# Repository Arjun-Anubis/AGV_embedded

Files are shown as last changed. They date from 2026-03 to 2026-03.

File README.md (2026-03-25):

# AGV Embedded Systems Selection Round

I attempted the first two tasks, the PCB design of the nPM1100 and the digital design of CORDIC in verilog

## Structure of the Repository

The task folders each have their directories, within the first level, the README.md
will have the info required to run the programs including installation directions etc
The documentation and approach will be in the doc folder

## Progress on the tasks

### PCB design

1. Base task (design req)
    a. Schematic
    b. Design 
    c. BOM
2. Expose CHG, ERR, ISET, MODE, SHPHLD and SHPACT pins to MCU
3. Status LEDs
4. Battery Monitoring

Constraints
1. Max Dimensions
2. SMD, top mounted
3. 0403-0805 footprints
4. Input via 2 pin header       NOTE
5. Max 4 copper layers
6. QFN24 footprint with used central thermal pad
7. 3V output
8. 200mA output

### Digital Design

1. Design
    a. n-bit adder
    b. complemts and subtracter
    c. comparator
    d. look up table
    e. 8 bit to 12 bit CORDIC
2. Test Bench
3. GTKWave

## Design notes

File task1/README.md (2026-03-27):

# PCB Design with the nPM1100 PMIC

This is documentaion written after the fact, if you want to read the 
design process as it was done, consider [the old readme](./README.old.md). 
I'll explain my model in two layers of abstraction.

1. Behaviour level
2. Pin level

## Behaviour level

A PMIC is typically used on a portable electronic device: like a mobile phone, 
a gaming mouse, a drone etc. it abstracts away the details of charging and battery
and provides a stable voltage and current to the microcontroller chip.

This means that our chip has the following

1. input (USB or barrel)
2. output (microcontroller)
3. inout (battery, which has to be charged and discharged)

and similarly out PMIC can itself be divided into subsystems

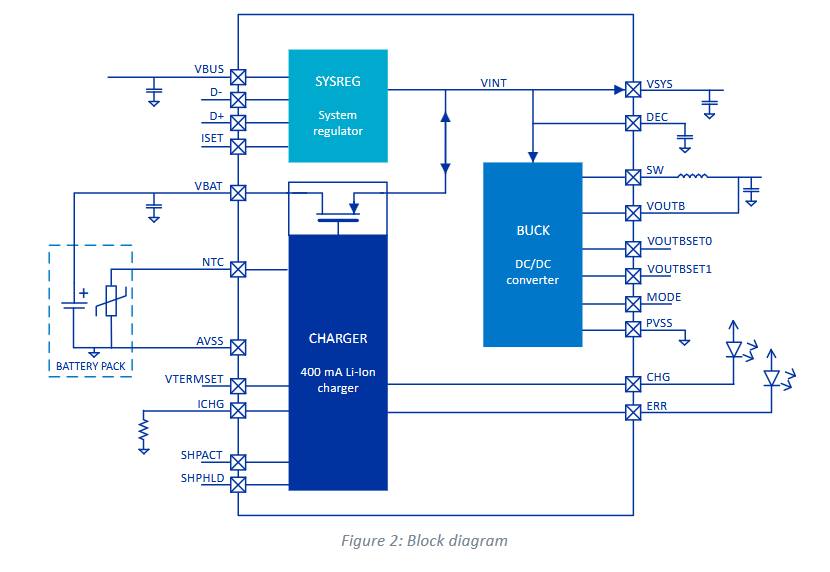
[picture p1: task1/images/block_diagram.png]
Block diagram


Now that we understand what the chip does on a high level, we need to check if this
is indeed the right chip for us to use, we can decide this by looking at the 
design requirements:

1. 3V DC output
2. 200mA charging
3. 35mmx35mm for the entire PCB

and we have been told to use the nordic semiconductor nPM1100 PMIC
with the QFN24 variant, which is 4mmx4mm.

First we make a ballpark estimate, then we consult the data sheet, the voltage ~ 3V
is pretty typical for a microcontroller so that makes sense, and the charging
current 200mA is pretty typical for a small LiPo battery, in say a drone.

The consumption current is probably less than that, and that would make the 
outut power a few hundred mW, which is also reasonable for a 35mmx35mm
chip to discharge

Now we consult the datasheet

### Package size

The 4mmx4mm package does indeed exist

> nPM1100 is an integrated Power Management IC (PMIC) with a linear-mode lithium-ion/lithium-polymer battery charger in a compact 2.1x2.1 mm WLCSP or 4.0x4.0 mm QFN package. It has a highly efficient DC/ DC buck regulator with configurable dual mode output.

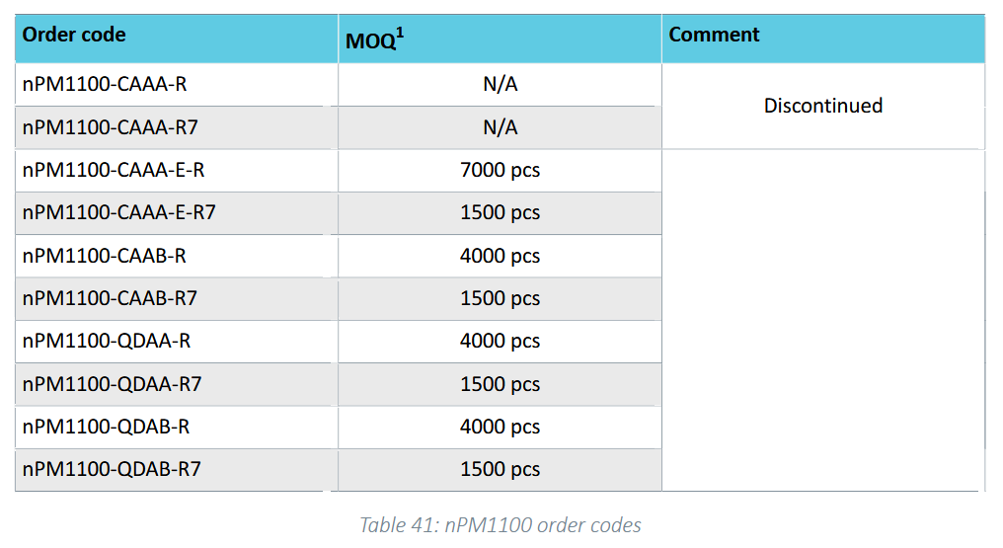
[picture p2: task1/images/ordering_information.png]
Ordering info


and we can indeed order it, according to the datasheet, the exact variant we want is

> nPM1100-QDAA-XX

where the QD portion signifies the QFN package, and AA specifies the Vterm voltage

### Charging Current

We can indeed charge at 200mA 

> Configurable charge current with a resistor connected to the ICHG pin (from 20 mA to 400 mA)

and we need to use a 1.5k resistor according to the table

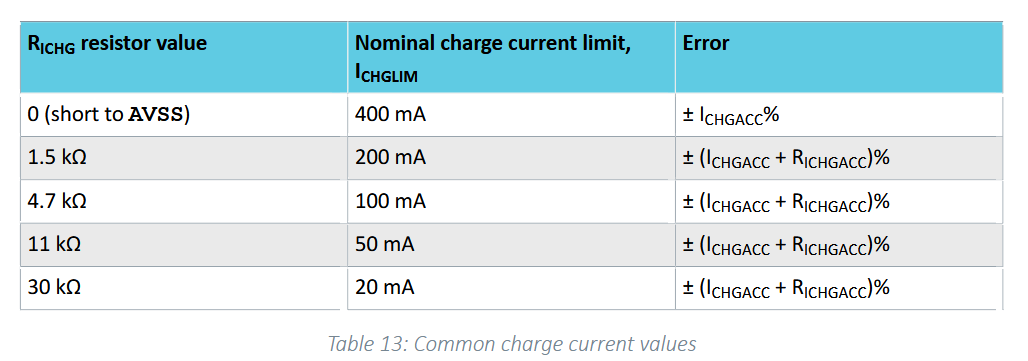
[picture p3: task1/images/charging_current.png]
charging current


### Output voltage

We can indeed output a stable 3.0V using the buck regulator

> Configurable output voltage between 1.8 V and 3.0 

and we need to set both VOUTBSET pins high accourding to the table

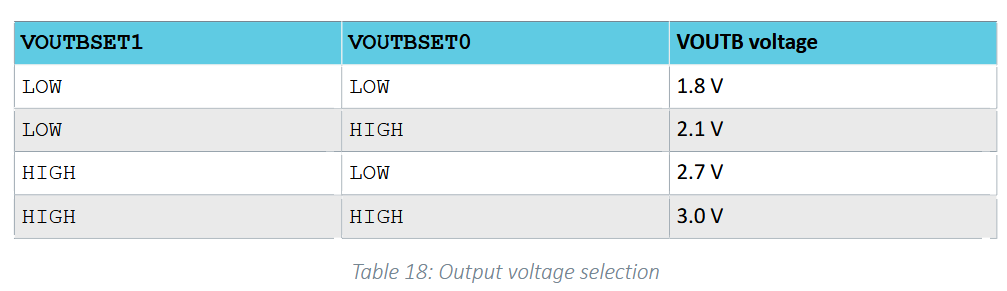
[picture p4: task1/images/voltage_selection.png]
voltage selection


## Pin Level

Now we have a high level overview of the scale and function of the chip, and we haev determined
that it can be appropriately used here, let us get into the nitty gritties. We need to make a few 
design choices

1. Which power input setting?

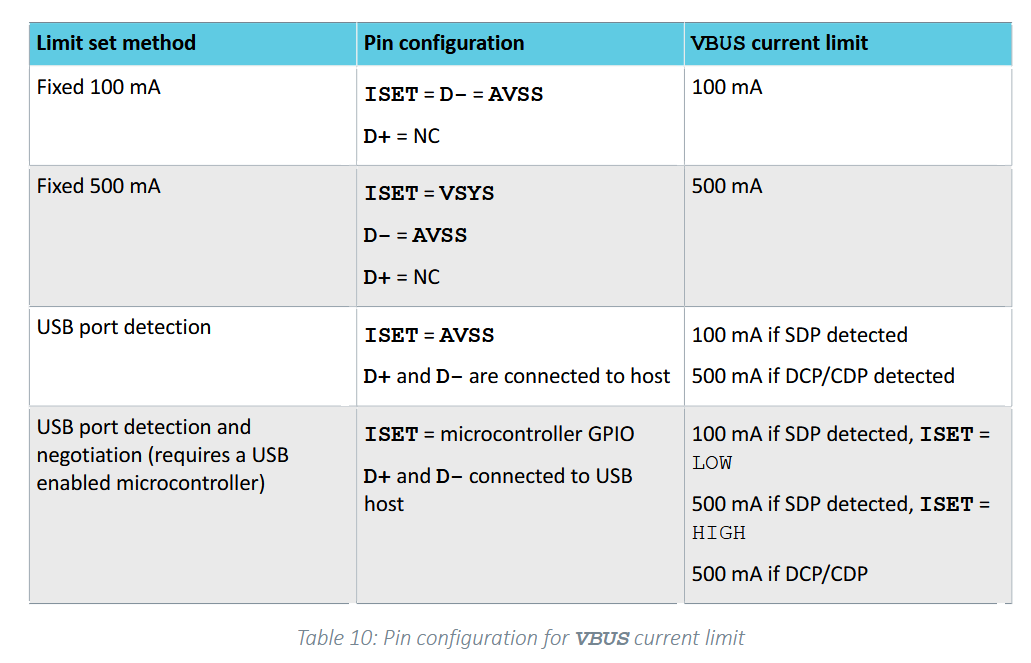
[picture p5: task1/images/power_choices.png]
Choices for power input


According to the datasheet, I can choose from four possible choices, of these I'm going to choose 
option 3, 

Why? Three reasons

a. We need atleast 200mA input for it to be able to charge the battery while also powering the device
and so I cant use the flat 100mA option
b. Flat 500mA is unsafe in the SDP case, in which case I risk bricking a laptop if I charge from that
essentially I wouldnt be following the USB spec
c. Exposing ISET requires (a) more pins to the MCU, and (b) also exposing the usb data line to the MCU
both of which, it may not have

2. Which battery parameters?
We need to set three parameters;

a. Ichg, which has to be 200mA and requires a 1.5k resistor (tolerance be damned :( )
b. Vtermset, which really depends on our battery, but I'll set it low, which is 4.1V cuz we're on standard
c. NTC, here I'll opt to just ignore this, because it seems that batteries with thermistors are rare
and it adds an extra pin, and we already need two pins for power and ground.

3. What sort of microcontoller header?

What do we absolutely need?
1. Vout
2. ground

What would be nice to have?
1. CHG
2. ERR

What would be _really_ nice to have?
1. Battery monitor with enable
2. Low battery indicator

What I'm not exposing?
1. MODE: why? the default is already automatic
2. ISET: I dont wanna expose the USB bus
3. SHPACT: too nihe a faeture to demand its own pin

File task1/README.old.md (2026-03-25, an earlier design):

# PCB Design with the nPM1100 PMIC

So at first glance, here's what I understand of this task. The company NordicSemiconductors makes an IC which is used for "power management", more specifically from their own [site](https://www.nordicsemi.com/Products/nPM1100)

> The nPM1100 is a dedicated power management IC (PMIC) with a highly efficient dual-mode configurable buck regulator and integrated battery charger. It is designed as a complementary component to Nordic’s nRF52® Series and nRF53® Series System-on-Chips (SoCs) to ensure reliable power delivery and stable operation, whilst maximizing battery life through high efficiency and low quiescent currents. It can also be used as a generic PMIC device for any other suitable application.

the issue as I see it is that this is an IC, and so its very small and the pins are not useable, I also assume a bunch of capacitors and resistors are probably needed which an IC can not incorporate, so we need to build a PCB around it. 

So, whats the gameplan then?

1. Find out what the hell "power management" is, what is a power management IC expected to do, this should give us the (abstract) spec for our PCB
2. Find out what interface the nPM1100 IC exposes, and form a more detailed spec of what this PCB is supposed to do
3. Find out how to design a PCB (yeah this is a pretty big step, but its hard to say how to break it down 

The nRF52 and 53 are SoC's, essentially a chip that performs all the tasks that are needed for a small computer like device like a phone, or television or something like that, so basically it needs to provide power to another IC. They're also saying something about an integrated battery charger and a dual mode configurable buck regulator.

So lets have a look at the datasheet, I found one at [mouser](https://www.mouser.com/datasheet/2/297/nPM1100_PS_v1_3-3114436.pdf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), but hey I read the PS again and apparently there's one on the main Nordic Site as well, but yeah they're the same thing, so it doesn't matter.

So there's a bunch of documents I should read apprently, but the trick I suppose is not to get lost in the weeds too long, the datasheet is supposed to be reference to cross check what I'm doing anyways

## Application Schematic

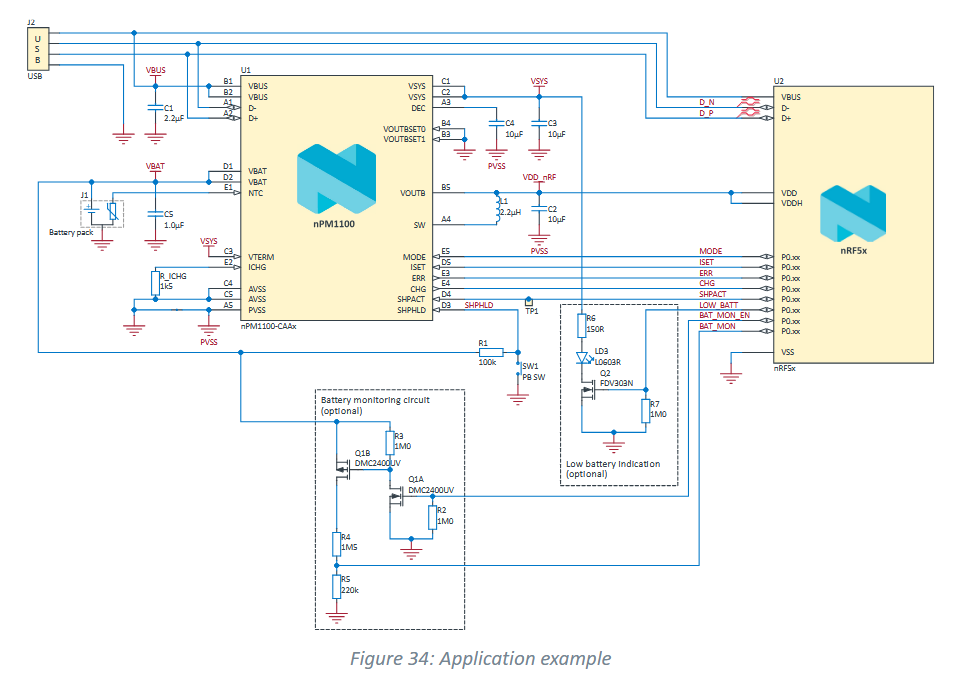
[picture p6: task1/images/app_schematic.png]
Application Scheme


Welp, here's what I found. Skip straight to chapter 7, application, which starts with a schematic that does make a lot of things clear. Its an example application of using the nPM1100 to drive a nR5X (2 or 3 ig) so we've got three 4 main elements

1. The nR52X, the thing we're driving. 
2. The USB input that's providing the power (when connected)
3. A battery, thats providing the power when the USB is not connected and getting charged when it is
4. The nPM1100 which does the following things

Lets talk about each of these things in turn, 

### The SoC: nRF5X
I don't really care what it does, we're more concerned about its inputs over here, 

#### Power Inputs
1. VSS, the source (as in MOS) voltage, or the reference ground in whatever flavour of MOS this is, I don't really care about the nomenclature here, the only thing to note is that this is the ground plane, but also make note of the fact that PVSS exists, which is the power ground, they're the same voltage, but they're connected differently to prevent noise coupling it seems (chatgpt)
2. VDD and VDDH, this is the input voltage that drives the chip, value is like 3V type shi, VDDH is a way to do some voltage regulation and allow higher voltage inputs, we don't really care since we're doing it using the buck regulator (chatgpt)
3. VBUS, D+ and D-, this is the USB interface of the chip itself, note that both and and the PMIC are both connected to the USB, VBUS is only used for detection (chatgpt) to tell when the usb is connected and the D+ and D- are data pins used for communication, again, the PMIC should handle most of this, but we'll get into the weeds of this later

> VBUS is supplied to both nPM1100 and nRF5x to supply nPM1100 SYSREG and the nRF5x VBUS regulator.
#### Indictor Pins
These are directly connected to the PMIC and have the same name, they basically do three major things, (a) set the desired voltage (the voltage itself is hard coded here it seems) regulation and current needed (b) check if the battery is charging (and if there's an error due to say, water damage) and (c) put the chip into shipping mode. Additionally, it also monitors the battery to detect if its low on charge.
1. CHG 		get battery charging state
2. ERR 		get battery charging error state
3. MODE 	set the type of voltage regulation (automatic or forced pwm, see page 46)
4. ISET 	set the current I need to charge safely (1 to 500mA, but it depends on what the charger is capable of too)
5. SHPACT 	set the PMIC into shipping mode (I'll talk about this in detail later)
6. LOW_BATT	get the low battery state (you need an external monitoring circuit tho)
7. BAT_MON 	Hold on

### The Input power: USB (or not, but USB in this example)
USB, the universal serial bus is a standard that refers to a lot of connectors, but we're talking specifically about USB2, which is very simple, it has 4 pins, 

1. VBus
2. D+
3. D-
4. Gnd

and thats it, later versions have gotttern increasingly more complex, but here's what we need to know, D+ and D- form a serial line that allows the charging device to talk to the PMIC and the SoCk, we'll get into the protocol if we have to, but as far as I'm concerned I'll just slap on a USB2 port on to my PCB and get these 4 lines out. (3 if you dont count ground)

You do need to know about 

> Port negotiation can be performed after nPM1100 port detection. The nRF5x device and nPM1100 are both connected to USB in the application example. nPM1100 detects SDP or CDP/DCP. If SDP is detected, the USB device can negotiate with the USB host for higher current from VBUS.

#### The Battery
In the schematic this is pretty simple, but there's two main things to note here 
1. The charging cycle itself is rather complicated and I'll get into it if I need to
2. NTC allows you to monitor the thermals of the battery itself, and thats a large part of the PMIC's job as well

#### The PMIC itself: nPM1100
This ofcourse, deserves its own readme, all to itself, so I'll break down the matter later. But for now, I think I understand well enough what this IC does, we now need to either making a spec, or looking at how to fabricate a PCB

## Reference Circuits
On the first front, I can basically cheat, chapter 8 gives us a few example PCB circuits, 6 to be specific, 3 different levels of implementing the features and 2 different form factors (WLCSP or QFN), we're concerned with the QFN ones

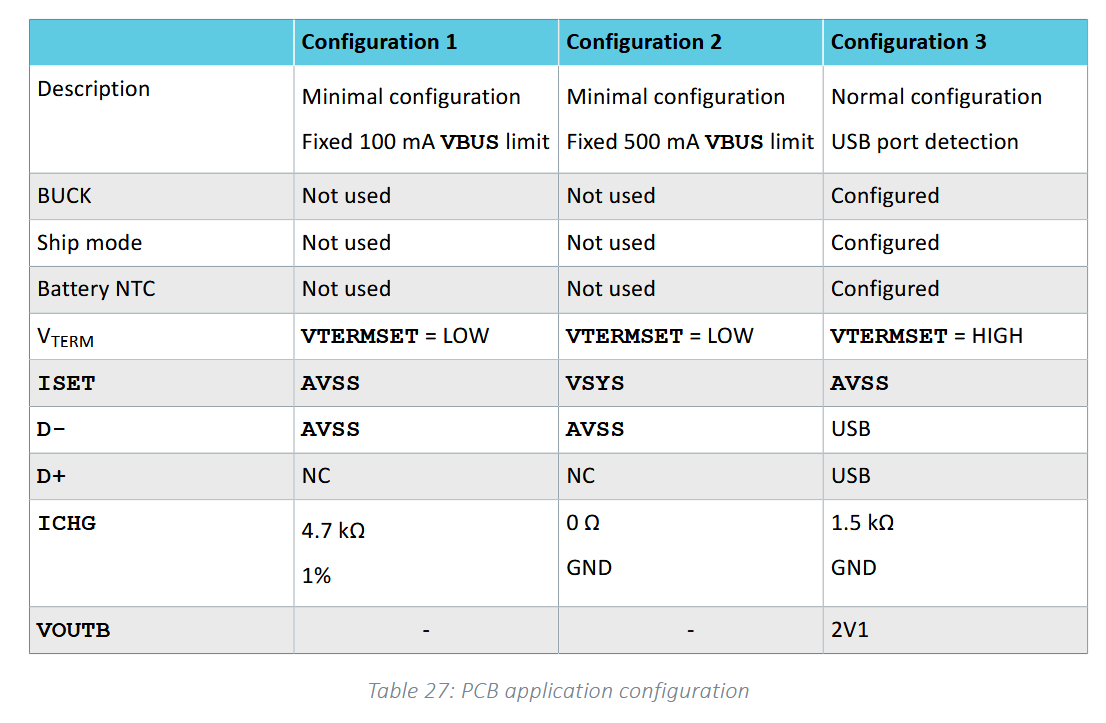
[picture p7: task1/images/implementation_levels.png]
implementation levels


Lets start with the most basic model, this is really very bare bones, it doesn't use the USB in, it doesnt use the V buck, no shipping, optional charging led, no thermal  regulation. 

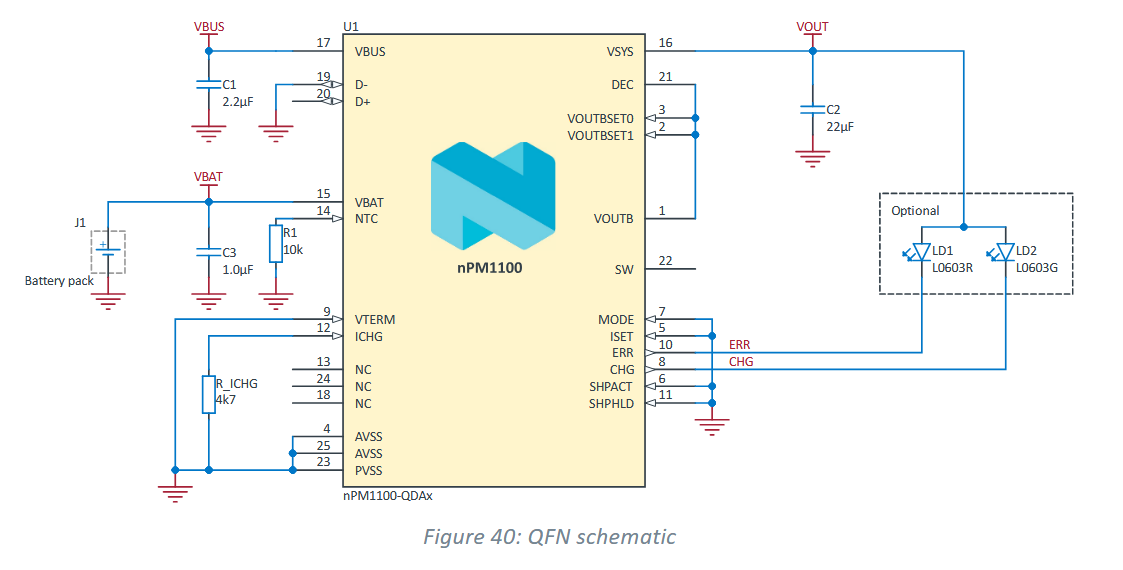
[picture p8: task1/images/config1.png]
config1


So for now I can focus on just implementing this, excellent, saves the reading for later. How do you implement this schematic on a PCB?
So for no

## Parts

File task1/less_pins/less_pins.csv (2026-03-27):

Reference | Qty | Value | DNP | Exclude from BOM | Exclude from Board | Footprint | Datasheet
C1,C3,C5 | 3 | 10u |  |  |  | Capacitor_SMD:C_0603_1608Metric | ~
C2 | 1 | 1u |  |  |  | Capacitor_SMD:C_0603_1608Metric | ~
C4 | 1 | 2.2u |  |  |  | Capacitor_SMD:C_0603_1608Metric | ~
D1,D2 | 2 | LED |  |  |  | LED_SMD:LED_0603_1608Metric | ~
IC1 | 1 | NPM1100-QDAA-R7 |  |  |  | npm1100lib:QFN50P400X400X90-25N-D | https://www.digikey.co.za/en/products/detail/nordic-semiconductor-asa/NPM1100-QDAA-R7/18069439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
J1 | 1 | USB_B_Micro |  |  |  | Connector_USB:USB_Micro-B_Amphenol_10104110_Horizontal | ~
J2 | 1 | Power Header |  |  |  | Connector_PinSocket_2.54mm:PinSocket_1x02_P2.54mm_Vertical | ~
J3 | 1 | Battery Header |  |  |  | Connector_JST:JST_PH_B2B-PH-K_1x02_P2.00mm_Vertical | ~
L1 | 1 | L |  |  |  | Inductor_SMD:L_0603_1608Metric | ~
R1 | 1 | R |  |  |  | Resistor_SMD:R_0603_1608Metric | ~
R2 | 1 | 1.5k |  |  |  | Resistor_SMD:R_0603_1608Metric | ~

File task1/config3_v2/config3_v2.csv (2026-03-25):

Id | Designator | Footprint | Quantity | Designation | Supplier and ref
1 | IC1 | QFN50P400X400X90-25N-D | 1 | NPM1100-QDAA-R7
2 | C1 | C_0603_1608Metric | 1 | 1u
3 | C2,C4,C5 | C_0603_1608Metric | 3 | 10u
4 | C3 | C_0603_1608Metric | 1 | 2.2u
5 | R2 | R_0603_1608Metric | 1 | 10k
6 | R1 | R_0603_1608Metric | 1 | 1.5k
7 | L1 | L_0805_2012Metric | 1 | 2.2u
8 | J3 | USB_Micro-B_Amphenol_10118194_Horizontal | 1 | USB_B_Micro
9 | J2 | PinSocket_1x08_P2.54mm_Vertical | 1 | MCU Connector
10 | J1 | JST_PH_B2B-PH-K_1x02_P2.00mm_Vertical | 1 | BatteryCon

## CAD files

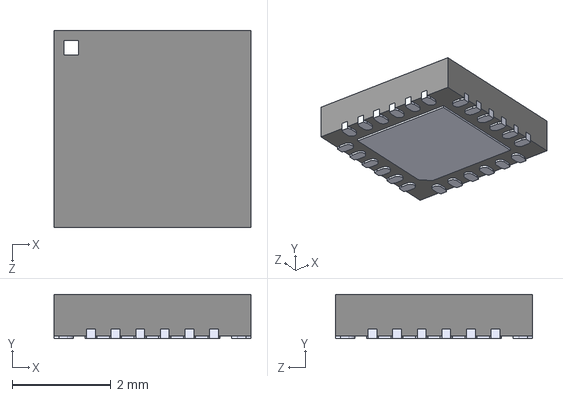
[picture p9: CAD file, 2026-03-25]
task1/config3/NPM1100-QDAB-R7/NPM1100-QDAB-R7.step
4.00 x 0.9 x 4.00 mm

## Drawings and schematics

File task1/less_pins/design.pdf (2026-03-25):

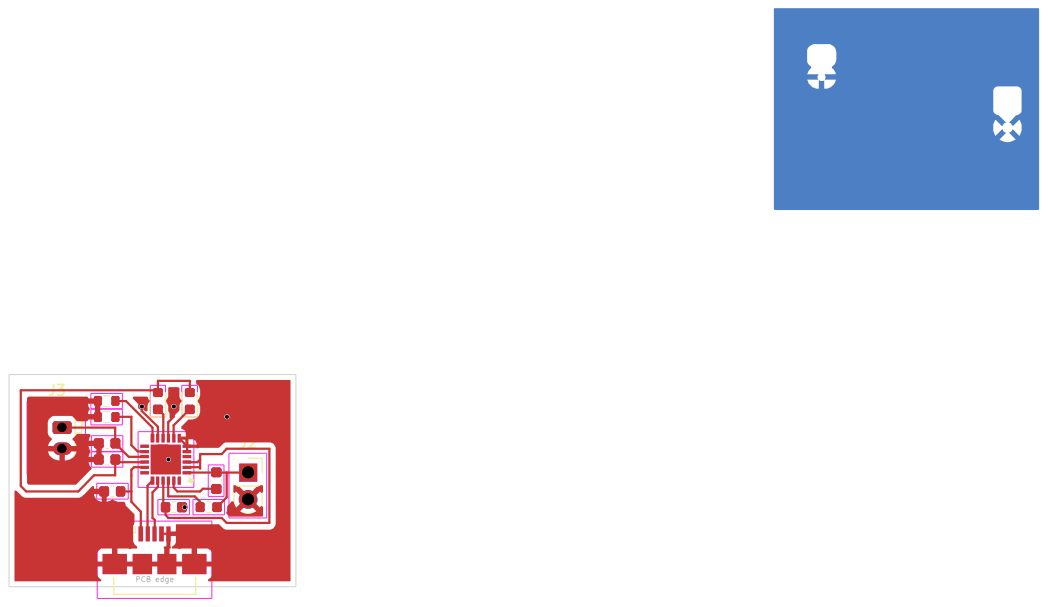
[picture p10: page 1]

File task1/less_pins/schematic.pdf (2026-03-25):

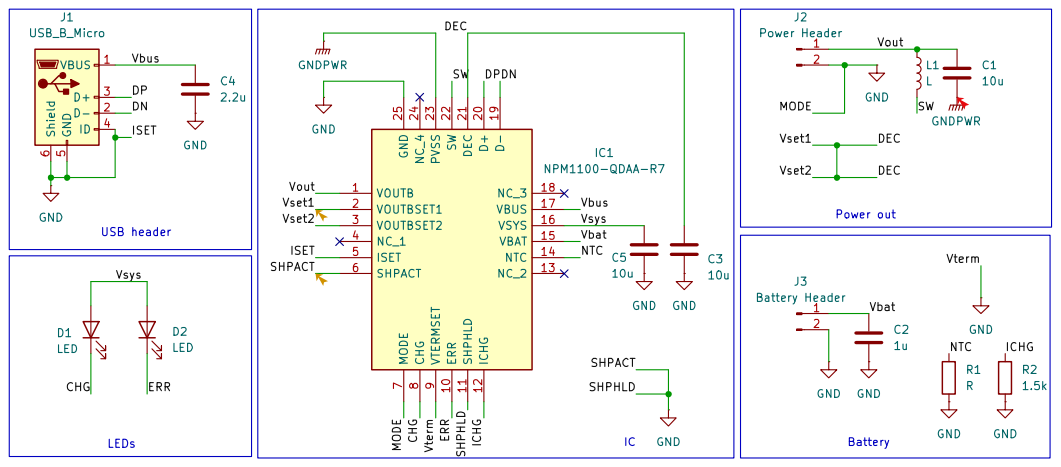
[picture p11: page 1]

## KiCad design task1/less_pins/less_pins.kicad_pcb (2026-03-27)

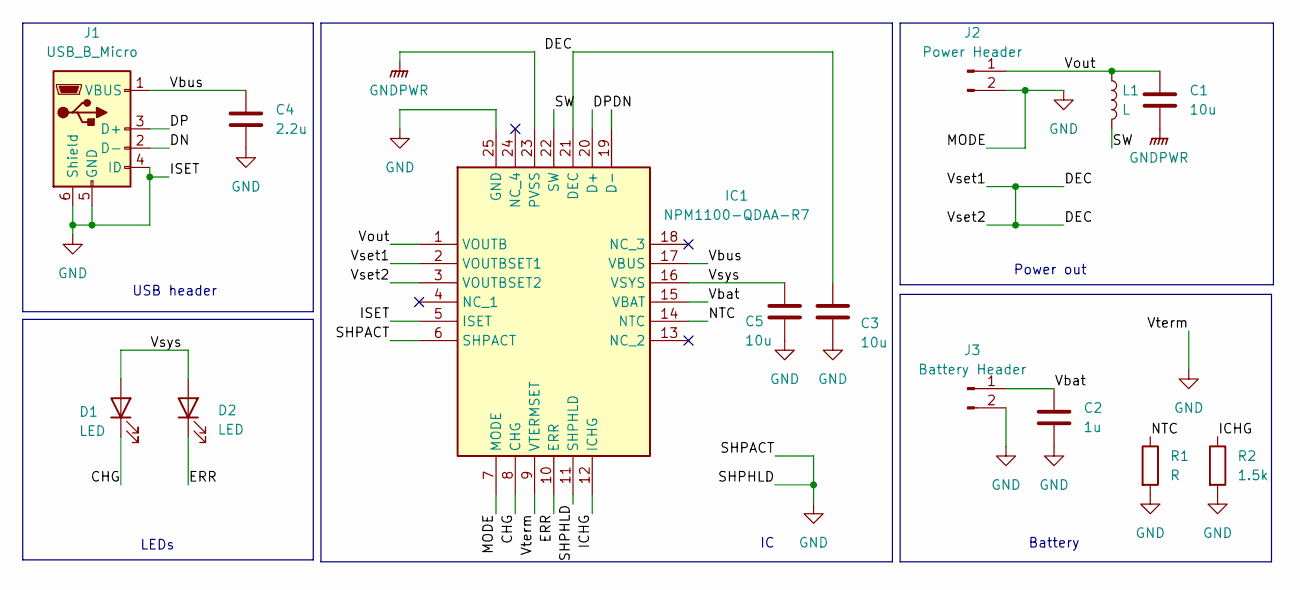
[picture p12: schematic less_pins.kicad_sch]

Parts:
C1, C3, C5: 10u; C_0603_1608Metric
C2: 1u; C_0603_1608Metric
C4: 2.2u; C_0603_1608Metric
D1, D2: LED; LED_0603_1608Metric
IC1: NPM1100-QDAA-R7; QFN50P400X400X90-25N-D; Mouser Part Number 949-NPM1100-QDAA-R7
J1: USB_B_Micro; USB_Micro-B_Amphenol_10104110_Horizontal
J2: Power Header; PinSocket_1x02_P2.54mm_Vertical
J3: Battery Header; JST_PH_B2B-PH-K_1x02_P2.00mm_Vertical
L1: L; L_0603_1608Metric
R1: R; R_0603_1608Metric
R2: 1.5k; R_0603_1608Metric

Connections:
/CHG: D1.1 (K), IC1.8 (CHG)
/DEC: C3.1, IC1.2 (VOUTBSET1), IC1.3 (VOUTBSET2), IC1.21 (DEC)
/DN: IC1.19 (D-), J1.2 (D-)
/DP: IC1.20 (D+), J1.3 (D+)
/ERR: D2.1 (K), IC1.10 (ERR)
/ICHG: IC1.12 (ICHG), R2.1
/NTC: IC1.14 (NTC), R1.1
/SW: IC1.22 (SW), L1.2
/Vbat: C2.1, IC1.15 (VBAT), J3.1
/Vbus: C4.1, IC1.17 (VBUS), J1.1 (VBUS)
/Vout: C1.1, IC1.1 (VOUTB), J2.1, L1.1
/Vsys: C5.2, D1.2 (A), D2.2 (A), IC1.16 (VSYS)
GND: C2.2, C3.2, C4.2, C5.1, IC1.5 (ISET), IC1.6 (SHPACT), IC1.7 (MODE), IC1.9 (VTERMSET), IC1.11 (SHPHLD), IC1.25 (GND), J1.4 (ID), J1.5 (GND), J1.6 (Shield), J2.2, J3.2, R1.2, R2.2
GNDPWR: C1.2, IC1.23 (PVSS)

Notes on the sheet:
LEDs
Battery
USB header
Power out

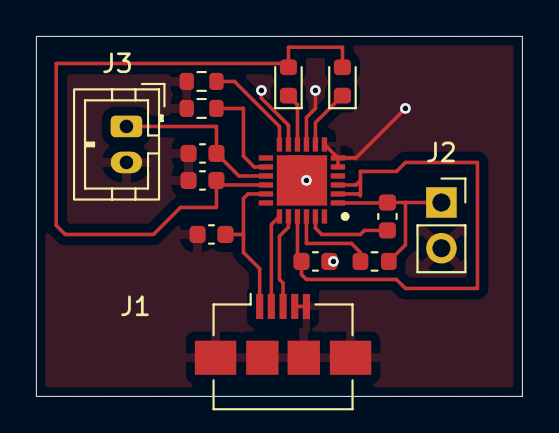
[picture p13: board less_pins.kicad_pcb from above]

Board: 2 copper layers, 27.0 x 20.0 mm, 14 parts (0 on the bottom side), 14 nets.

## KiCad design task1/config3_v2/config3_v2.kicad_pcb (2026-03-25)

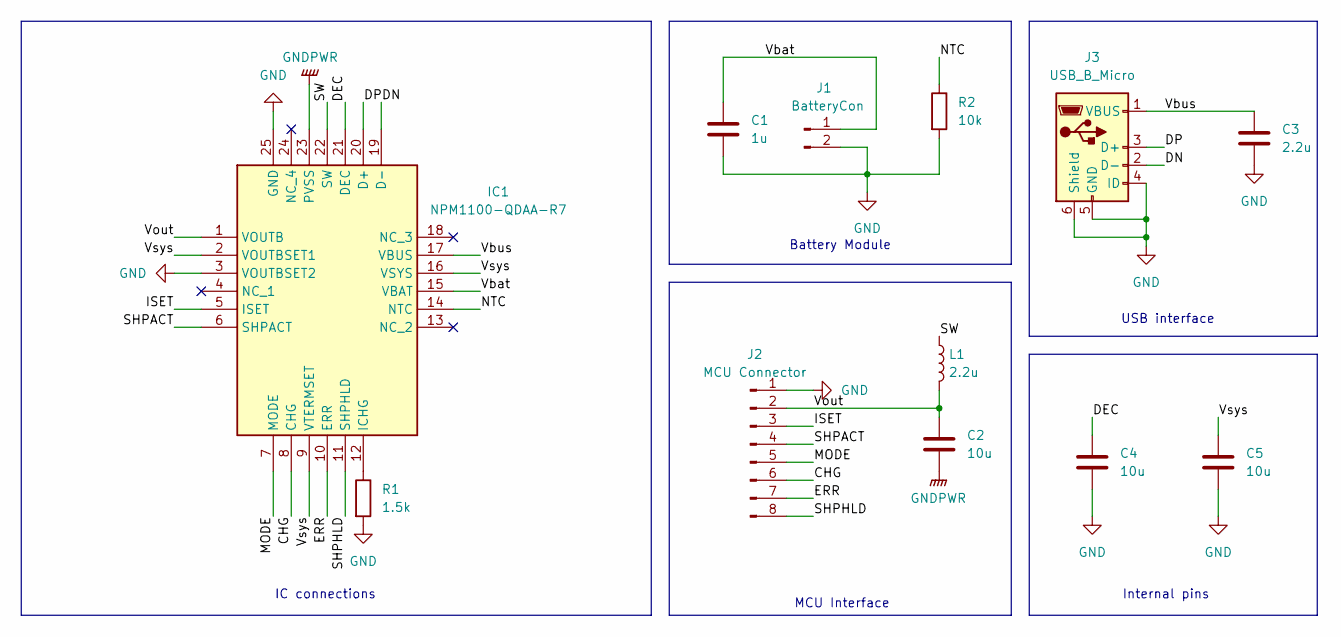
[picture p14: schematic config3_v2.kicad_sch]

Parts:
C1: 1u; C_0603_1608Metric
C2, C4, C5: 10u; C_0603_1608Metric
C3: 2.2u; C_0603_1608Metric
IC1: NPM1100-QDAA-R7; QFN50P400X400X90-25N-D; Mouser Part Number 949-NPM1100-QDAA-R7
J1: BatteryCon; JST_PH_B2B-PH-K_1x02_P2.00mm_Vertical
J2: MCU Connector; PinSocket_1x08_P2.54mm_Vertical
J3: USB_B_Micro; USB_Micro-B_Amphenol_10118194_Horizontal
L1: 2.2u; L_0805_2012Metric
R1: 1.5k; R_0603_1608Metric
R2: 10k; R_0603_1608Metric

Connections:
/CHG: IC1.8 (CHG), J2.6
/DEC: C4.1, IC1.21 (DEC)
/DN: IC1.19 (D-), J3.2 (D-)
/DP: IC1.20 (D+), J3.3 (D+)
/ERR: IC1.10 (ERR), J2.7
/ISET: IC1.5 (ISET), J2.3
/MODE: IC1.7 (MODE), J2.5
/NTC: IC1.14 (NTC), R2.1
/SHPACT: IC1.6 (SHPACT), J2.4
/SHPHLD: IC1.11 (SHPHLD), J2.8
/SW: IC1.22 (SW), L1.1
/Vbat: C1.1, IC1.15 (VBAT), J1.1
/Vbus: C3.1, IC1.17 (VBUS), J3.1 (VBUS)
/Vout: C2.1, IC1.1 (VOUTB), J2.2, L1.2
/Vsys: C5.1, IC1.2 (VOUTBSET1), IC1.9 (VTERMSET), IC1.16 (VSYS)
GND: C1.2, C3.2, C4.2, C5.2, IC1.3 (VOUTBSET2), IC1.25 (GND), J1.2, J2.1, J3.4 (ID), J3.5 (GND), J3.6 (Shield), R1.2, R2.2
GNDPWR: C2.2, IC1.23 (PVSS)
unnamed: IC1.12 (ICHG), R1.1

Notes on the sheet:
USB interface
Battery Module
MCU Interface
Internal pins
IC connections

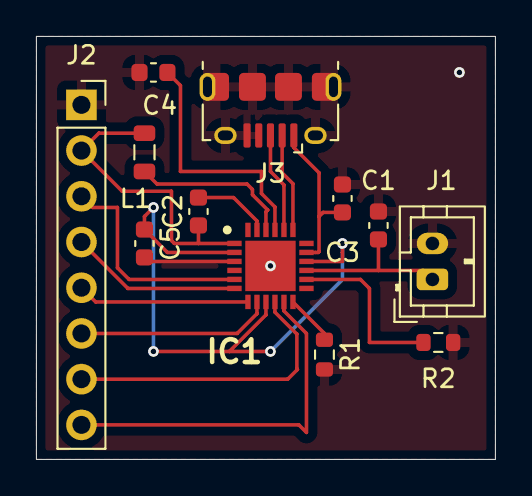
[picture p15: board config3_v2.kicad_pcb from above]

Board: 2 copper layers, 25.5 x 23.5 mm, 12 parts (0 on the bottom side), 18 nets.

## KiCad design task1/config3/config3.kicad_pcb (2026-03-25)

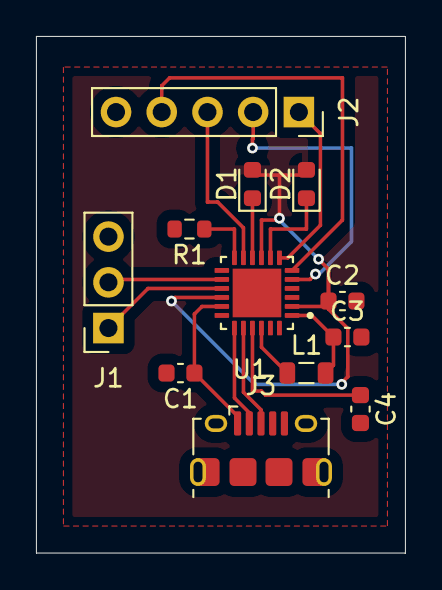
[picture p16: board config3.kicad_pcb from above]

Board: 2 copper layers, 20.5 x 28.7 mm, 12 parts (0 on the bottom side), 17 nets.

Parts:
C1: 2.2u; C_0603_1608Metric
C2, C3, C4: 10u; C_0603_1608Metric
D1, D2: LED; LED_0603_1608Metric
J1: BatteryConnector; PinSocket_1x03_P2.54mm_Vertical
J2: OutputInterface; PinSocket_1x05_P2.54mm_Vertical
J3: USB_B_Micro; USB_Micro-B_Amphenol_10118194_Horizontal
L1: L; L_0805_2012Metric
R1: 1.5k; R_0603_1608Metric
U1: NPM1100-QDAB-R7; QFN50P400X400X90-25N

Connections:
/DEC: C4.1, U1.21 (DEC)
/DN: J3.2 (D-), U1.19 (D-)
/DP: J3.3 (D+), U1.20 (D+)
/ISET: J2.2, U1.5 (ISET)
/MODE: J2.1, U1.7 (MODE)
/NTC: J1.2, U1.14 (NTC)
/SHPACT: J2.4, U1.6 (SHPACT)
/SHPHLD: J2.3, U1.11 (SHPHLD)
/Vbat: J1.1, U1.15 (VBAT)
/Vbus: C1.1, J3.1 (VBUS), U1.17 (VBUS)
/Vout: C3.1, L1.2, U1.1 (VOUTB)
/Vsys: C2.1, D1.2 (A), D2.2 (A), U1.2 (VOUTBSET1), U1.9 (VTERMSET), U1.16 (VSYS)
GND: C1.2, C2.2, C3.2, C4.2, J1.3, J2.5, J3.5 (GND), J3.6 (Shield), R1.2, U1.3 (VOUTBSET2), U1.23 (PVSS), U1.25 (EXP)
unnamed: D1.1 (K), U1.10 (ERR)
unnamed: D2.1 (K), U1.8 (CHG)
unnamed: R1.1, U1.12 (ICHG)
unnamed: L1.1, U1.22 (SW)

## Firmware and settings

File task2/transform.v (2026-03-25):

module Tp(
	input [12:0] x, y,
	input [7:0] counter,
	output [12:0] x_out, y_out
);
	wire cout;
	adder #(.N(13)) a1(
		.cin(1'b0),
		.cout(cout),
		.a(y),
		.b( x >> counter ),
		.sum( y_out)
	);
	adder #(.N(13)) a2(
		.cin(1'b1),
		.cout(cout),
		.a(x),
		.b( ~(y >> counter) ),
		.sum( x_out )
	);
endmodule

module Tn(
	input [12:0] x, y,
	input [7:0] counter,
	output [12:0] x_out, y_out
);
	wire cout;
	adder #(.N(13)) a1(
		.cin(1'b0),
		.cout(cout),
		.a(x),
		.b( y >> counter ),
		.sum( x_out )
	);
	adder #(.N(13)) a2(
		.cin(1'b1),
		.cout(cout),
		.a(y),
		.b( ~(x >> counter) ),
		.sum( y_out )
	);
endmodule

module Ap( input [8:0] in, input [7:0] counter, output [8:0] out );
	wire cout;
	reg [8:0] gamma [8:0];
	initial begin
		gamma[0] = 9'd127;
		gamma[1] = 9'd75;
		gamma[2] = 9'd40;
		gamma[3] = 9'd20;
		gamma[4] = 9'd10;
		gamma[5] = 9'd5;
		gamma[6] = 9'd3;
		gamma[7] = 9'd1;

	end
	adder #(.N(9)) a( .cin(1'b1), .cout(cout), .a(in), .b(~gamma[counter]), .sum(out));
	// assign out = in - gamma[counter];
endmodule

module An( input [8:0] in, input [7:0] counter, output [8:0] out );
	wire cout;
	reg [8:0] gamma [8:0];
	initial begin
		gamma[0] = 9'd127;
		gamma[1] = 9'd75;
		gamma[2] = 9'd40;
		gamma[3] = 9'd20;
		gamma[4] = 9'd10;
		gamma[5] = 9'd5;
		gamma[6] = 9'd3;
		gamma[7] = 9'd1;

	end
	adder #(.N(9)) a( .cin(1'b0), .cout(cout), .a(in), .b(gamma[counter]), .sum(out));
endmodule

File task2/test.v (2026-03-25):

module cordic( input clock, input [7:0] angle, input reset, output reg [11:0] sin_out, cos_out, output reg done );
	reg [7:0] counter;
	reg [8:0] full_angle;
	reg [7:0] gamma [0:7];

	reg [12:0] x, y, temp;


	initial begin 
		gamma[0] = 8'd127;
		gamma[1] = 8'd75;
		gamma[2] = 8'd40;
		gamma[3] = 8'd20;
		gamma[4] = 8'd10;
		gamma[5] = 8'd5;
		gamma[6] = 8'd3;
		gamma[7] = 8'd1;

	end
	always @(posedge clock or posedge reset) begin 

		if ( reset ) begin
			$display("Resetting counter & angle"); 
			counter = 0;
			full_angle = angle;
			x = 13'h9B7;
			y = 13'h0;
			$display("Initial: angle = %d, gamma = %d, x = %d, y = %d", full_angle, gamma[counter], x, y );
			$display("Reset"); 
		end

		else begin
			if ( counter[3] ) begin
				done = 1;
				@(posedge clock);
				done = 0;	
			end
			else begin
				temp = y;
				if ( full_angle[8] ) begin
					full_angle = full_angle + gamma[counter];
					y = y - (x>>counter);
					x = x + (temp>>counter);
				end
				else begin
					full_angle = full_angle - gamma[counter];
					y = y + (x>>counter);
					x = x - (temp>>counter);
				end

				$display("%d: angle = %d, gamma = %d, x = %d, y = %d", counter, full_angle, gamma[counter], x, y );

				counter = counter + 1;
				sin_out <= y[11:0];
				cos_out <= x[11:0];
			end

		end

	end
endmodule

module test_bench();
	reg clock;
	reg reset;
	wire done;
	reg [7:0] angle;
	wire [11:0] sin_out, cos_out;
	integer i;
	cordic my_cordic( .clock( clock ), .angle(angle), .sin_out(sin_out), .cos_out(cos_out), .reset(reset), .done(done) );
	initial begin 
		clock = 0;
		repeat(1000) begin
			#10 clock = ~clock;
		end
	end
	initial begin
		for (i = 0; i < 100; i = i + 10) begin
			angle = i;
			reset = 1;
			@(posedge clock);
			reset = 0;	
			@( posedge done )  begin $display ("sin(%d) = %d, cos(%d) = %d", angle, sin_out, angle, cos_out ); end
			@( negedge done );
		end
		
	end
endmodule

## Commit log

2026-03-10 Added referece circuit config 1
2026-03-25 Added verilog task
    [NPM1100-QDAB-R7.step, config3.kicad_pcb, config3.kicad_sch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]
2026-03-25 Added the whole project
    [less_pins.kicad_pcb, less_pins.kicad_sch]
2026-03-27 added a new build
    [exposed_pins.kicad_pcb, exposed_pins.kicad_sch, less_pins.csv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]
